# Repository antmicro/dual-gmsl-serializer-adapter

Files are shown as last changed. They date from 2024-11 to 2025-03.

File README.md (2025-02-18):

# Dual Camera to GMSL Serializer CSI Adapter

Copyright (c) 2024-2025 [Antmicro](https://www.antmicro.com)

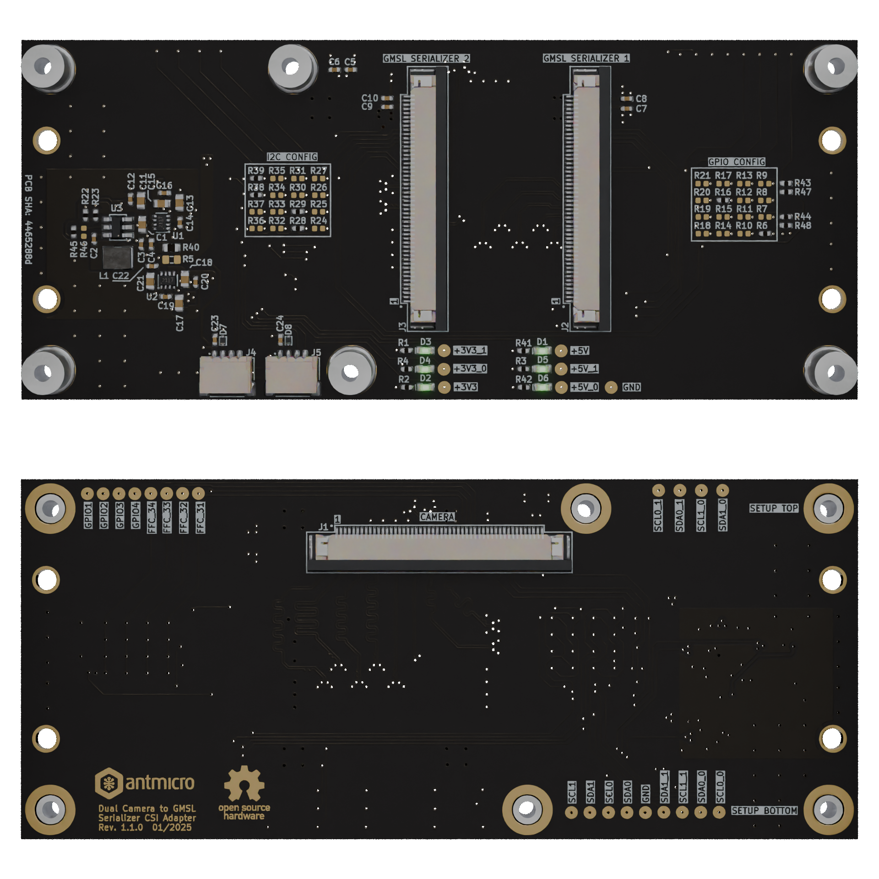
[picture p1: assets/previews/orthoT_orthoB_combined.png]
Dual Camera to GMSL Serializer CSI Adapter visualization


## Overview

This project provides open hardware design files for the Dual Camera to GMSL Serializer CSI Adapter. 
The board is designed to receive two MIPI CSI-2 x2 signals from the [OV5640 Dual Camera Board](https://github.com/antmicro/ov5640-dual-camera-board) and output them to two [GMSL Serializer Boards](https://github.com/antmicro/gmsl-serializer).
The on-board power distribution circuit allows the Dual Camera Board to be powered by one of the selected serializer boards.
The design files were prepared using KiCad 8.x.

## Key features

* 50-pin FFC input connector for the Dual Camera Board connection, exposing two 4-lane MIPI CSI-2 interfaces
* Two 50-pin FFC output connectors for the GMSL Serializer Boards, each supporting a 4-lane MIPI CSI-2 interface
* Two QWIIC connectors for seamless integration of additional I²C devices

## Project structure

The main directory includes KiCad PCB project files, a LICENSE, and a README.
The remaining files are stored in the following directories:

* ``doc`` - contains schematics in PDF format
* ``assets`` - contains visual assets for showcasing this design on [Open Hardware Portal](https://openhardware.antmicro.com) and [System Designer](https://designer.antmicro.com/welcome)

## Licensing

This project is published under the [Apache-2.0](LICENSE) license.

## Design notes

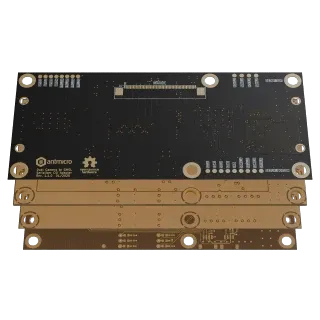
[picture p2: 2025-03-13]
assets/previews/layer1_thumbnail.webp

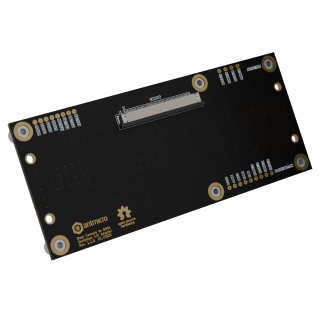
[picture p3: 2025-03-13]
assets/previews/leftT_thumbnail.png

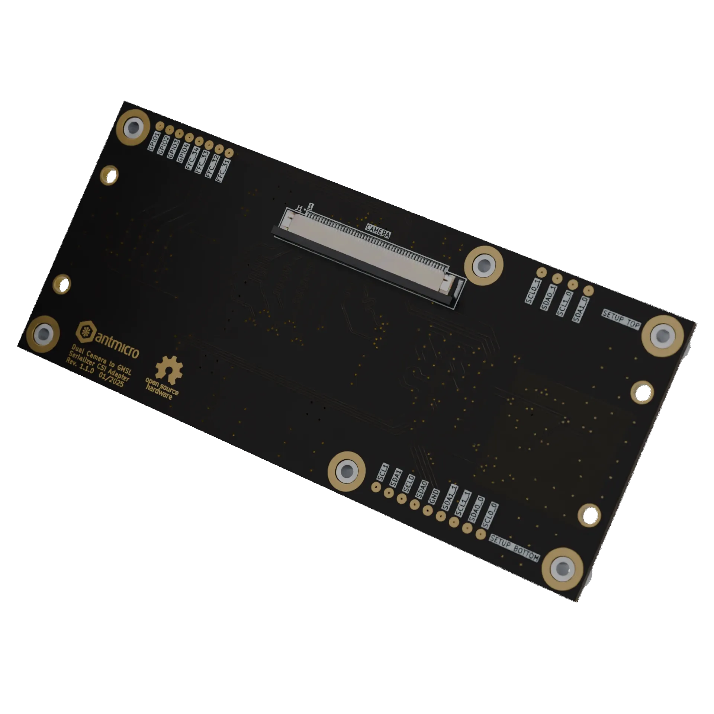
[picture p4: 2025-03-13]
assets/previews/rightT.webp

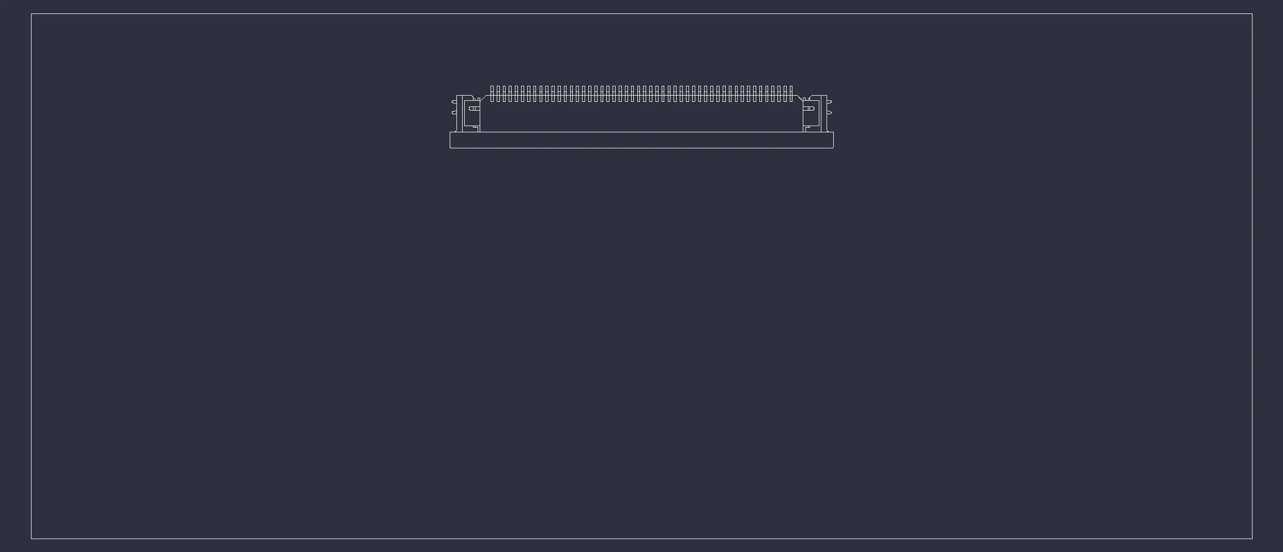
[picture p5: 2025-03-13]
assets/wireframe/wireframe_descriptions_top.webp

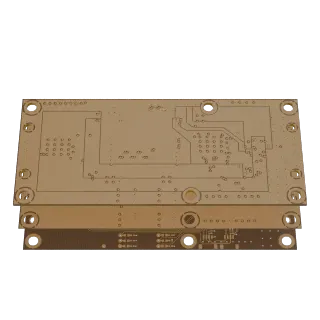
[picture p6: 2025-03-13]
assets/previews/layer3_thumbnail.webp

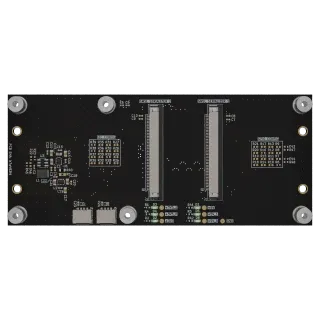
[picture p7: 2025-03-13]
assets/previews/orthoB_thumbnail.webp

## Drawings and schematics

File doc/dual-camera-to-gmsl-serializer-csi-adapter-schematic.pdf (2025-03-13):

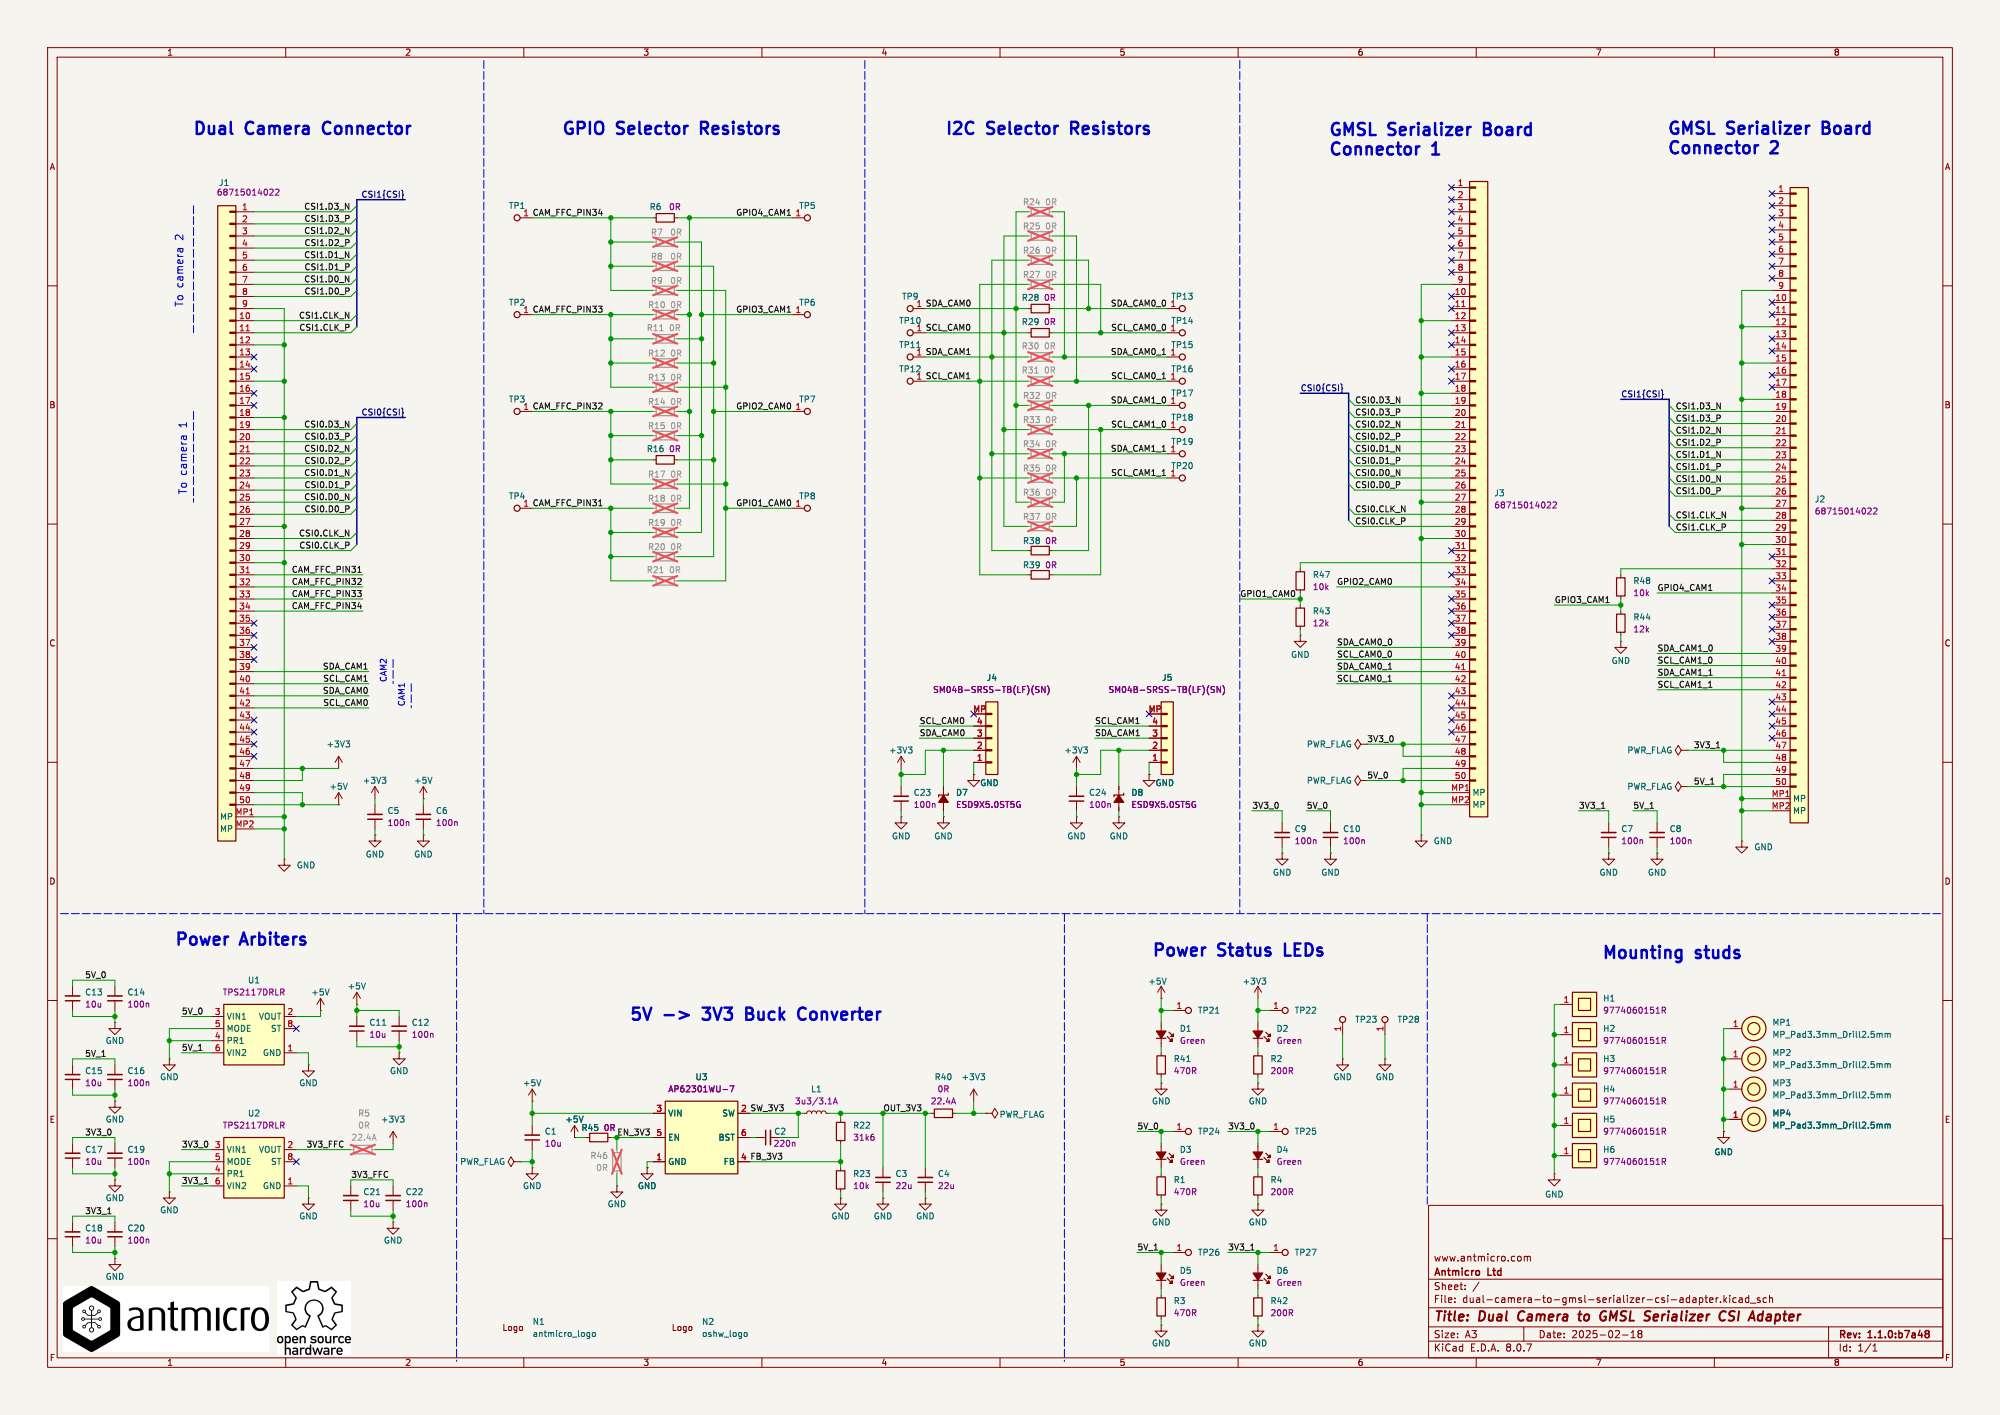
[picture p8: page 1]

J5 SM04B-SRSS-TB(LF)(SN) R37 0R

J4 SM04B-SRSS-TB(LF)(SN) 1

J5 SM04B-SRSS-TB(LF)(SN) 1

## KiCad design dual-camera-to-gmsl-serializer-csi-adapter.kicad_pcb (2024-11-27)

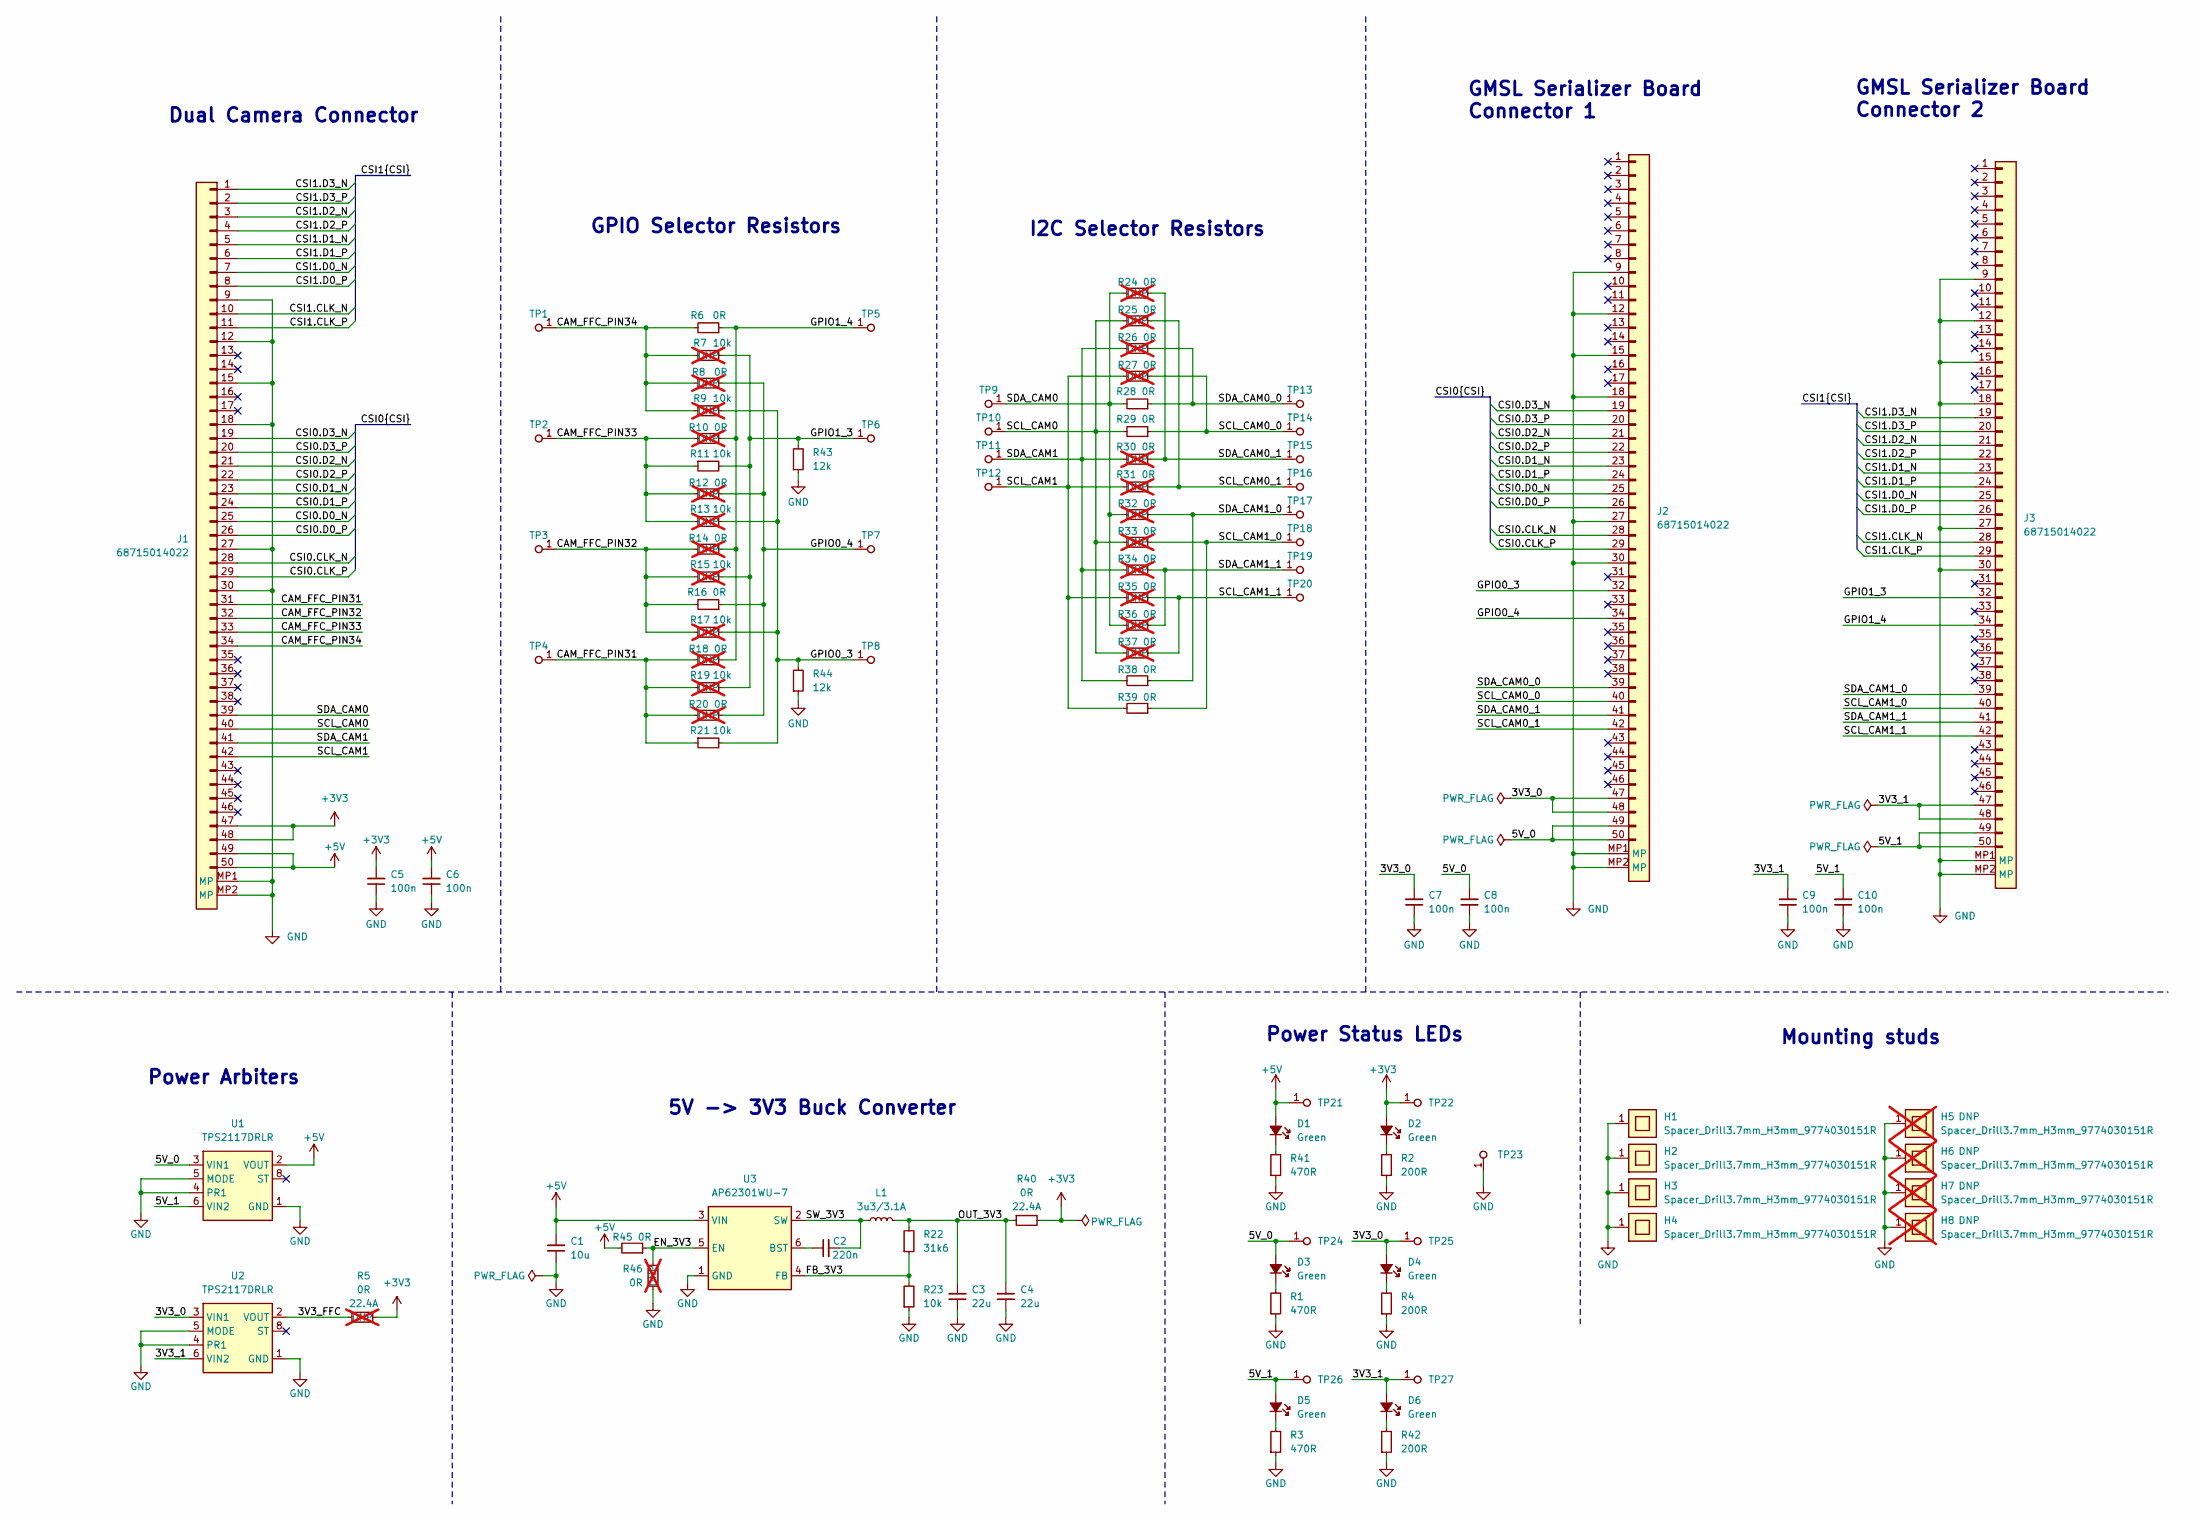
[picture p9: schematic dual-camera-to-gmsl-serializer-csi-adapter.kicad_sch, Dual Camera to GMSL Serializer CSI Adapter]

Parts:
C1: C_10u_25V_0603; C_0603_1608Metric; Voltage 25V; MPN C1608X5R1E106M080AC
C2: C_220n_0402; C_0402_1005Metric; MPN CC0402KRX5R6BB224
C3, C4: C_22u_0402; C_0402_1005Metric; MPN GRM158R60J226ME01D
C5, C6, C7, C8, C9, C10: C_100n_0402; C_0402_1005Metric; Voltage 50V; MPN GRM155R61H104KE14D
D1, D2, D3, D4, D5, D6: LED_G_0603_LTST-C190GKT; LED_0603_1608Metric_G; MPN LTST-C190GKT
H1, H2, H3, H4: Spacer_Drill3.7mm_H3mm_9774030151R; MPN 9774030151R
H5, H6, H7, H8: Spacer_Drill3.7mm_H3mm_9774030151R; MPN 9774030151R; not fitted
J1, J2, J3: Conn_FFC_WE_68715014022; Conn_FFC_WE_68715014x22; MPN 68715014022
L1: L_3u3_3.1A_Bourns-SRP3212A; L_Bourns-SRP3212A; MPN SRP3212-3R3M
R1, R3, R41: R_470R_0402; R_0402_1005Metric; Tolerance 1%; MPN CR0402-FX-4700GLF
R2, R4, R42: R_200R_0402; R_0402_1005Metric; Tolerance 1%; MPN CR0402-FX-2000GLF
R5: R_0R_22.4A_0603; R_0603_1608Metric; Tolerance template_tolerance; MPN PMR03EZPJ000; not fitted
R6, R16, R28, R29, R38, R39, R45: R_0R_0402; R_0402_1005Metric; MPN ERJ2GE0R00X
R7, R9, R13, R15, R17, R19: R_10k_0402; R_0402_1005Metric; Tolerance 1%; MPN CR0402-FX-1002GLF; not fitted
R8, R10, R12, R14, R18, R20, R24, R25, R26, R27, R30, R31, R32, R33, R34, R35, R36, R37, R46: R_0R_0402; R_0402_1005Metric; MPN ERJ2GE0R00X; not fitted
R11, R21, R23: R_10k_0402; R_0402_1005Metric; Tolerance 1%; MPN CR0402-FX-1002GLF
R22: R_31k6_0402; R_0402_1005Metric; Tolerance 1%; MPN CR0402-FX-3162GLF
R40: R_0R_22.4A_0603; R_0603_1608Metric; Tolerance template_tolerance; MPN PMR03EZPJ000
R43, R44: R_12k_0402; R_0402_1005Metric; Tolerance 1%; MPN CR0402-FX-1202GLF
TP1, TP2, TP3, TP4, TP5, TP6, TP7, TP8, TP9, TP10, TP11, TP12, TP13, TP14, TP15, TP16, TP17, TP18, TP19, TP20, TP21, TP22, TP23, TP24, TP25, TP26, TP27: TP_1.5mm_SMD; TP_SMD_1.5mm
U1, U2: TPS2117DRLR; SOT-583; MPN TPS2117DRLR
U3: AP62301_TSOT; TSOT23-6; MPN AP62301WU-7

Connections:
+3V3: C5.2, D2.2 (A), J1.47, J1.48, R5.2, R40.2, TP22.1
+5V: C1.2, C6.2, D1.2 (A), J1.49, J1.50, R45.2, TP21.1, U1.2 (VOUT), U1.7 (VOUT), U3.3 (VIN)
/3V3_0: C7.2, D4.2 (A), J2.47, J2.48, TP25.1, U2.3 (VIN1)
/3V3_1: C9.2, D6.2 (A), J3.47, J3.48, TP27.1, U2.6 (VIN2)
/3V3_FFC: R5.1, U2.2 (VOUT), U2.7 (VOUT)
/5V_0: C8.2, D3.2 (A), J2.49, J2.50, TP24.1, U1.3 (VIN1)
/5V_1: C10.2, D5.2 (A), J3.49, J3.50, TP26.1, U1.6 (VIN2)
/CAM_FFC_PIN31: J1.31, R18.2, R19.1, R20.2, R21.1, TP4.1
/CAM_FFC_PIN32: J1.32, R14.2, R15.1, R16.2, R17.1, TP3.1
/CAM_FFC_PIN33: J1.33, R10.2, R11.1, R12.2, R13.1, TP2.1
/CAM_FFC_PIN34: J1.34, R6.2, R7.1, R8.2, R9.1, TP1.1
/CSI0.CLK_N: J1.28, J2.28
/CSI0.CLK_P: J1.29, J2.29
/CSI0.D0_N: J1.25, J2.25
/CSI0.D0_P: J1.26, J2.26
/CSI0.D1_N: J1.23, J2.23
/CSI0.D1_P: J1.24, J2.24
/CSI0.D2_N: J1.21, J2.21
/CSI0.D2_P: J1.22, J2.22
/CSI0.D3_N: J1.19, J2.19
/CSI0.D3_P: J1.20, J2.20
/CSI1.CLK_N: J1.10, J3.28
/CSI1.CLK_P: J1.11, J3.29
/CSI1.D0_N: J1.7, J3.25
/CSI1.D0_P: J1.8, J3.26
/CSI1.D1_N: J1.5, J3.23
/CSI1.D1_P: J1.6, J3.24
/CSI1.D2_N: J1.3, J3.21
/CSI1.D2_P: J1.4, J3.22
/CSI1.D3_N: J1.1, J3.19
/CSI1.D3_P: J1.2, J3.20
/EN_3V3: R45.1, R46.1, U3.5 (EN)
/FB_3V3: R22.1, R23.2, U3.4 (FB)
/GPIO0_3: J2.32, R9.2, R13.2, R17.2, R21.2, R44.2, TP8.1
/GPIO0_4: J2.34, R8.1, R12.1, R16.1, R20.1, TP7.1
/GPIO1_3: J3.32, R7.2, R11.2, R15.2, R19.2, R43.2, TP6.1
/GPIO1_4: J3.34, R6.1, R10.1, R14.1, R18.1, TP5.1
/OUT_3V3: C3.2, C4.2, L1.2, R22.2, R40.1
/SCL_CAM0: J1.40, R25.2, R29.2, R33.2, R37.2, TP10.1
/SCL_CAM0_0: J2.40, R27.1, R29.1, TP14.1
/SCL_CAM0_1: J2.42, R25.1, R31.1, TP16.1
/SCL_CAM1: J1.42, R27.2, R31.2, R35.2, R39.2, TP12.1
/SCL_CAM1_0: J3.40, R33.1, R39.1, TP18.1
/SCL_CAM1_1: J3.42, R35.1, R37.1, TP20.1
/SDA_CAM0: J1.39, R24.2, R28.2, R32.2, R36.2, TP9.1
/SDA_CAM0_0: J2.39, R26.1, R28.1, TP13.1
/SDA_CAM0_1: J2.41, R24.1, R30.1, TP15.1
/SDA_CAM1: J1.41, R26.2, R30.2, R34.2, R38.2, TP11.1
/SDA_CAM1_0: J3.39, R32.1, R38.1, TP17.1
/SDA_CAM1_1: J3.41, R34.1, R36.1, TP19.1
/SW_3V3: C2.2, L1.1, U3.2 (SW)
GND: C1.1, C3.1, C4.1, C5.1, C6.1, C7.1, C8.1, C9.1, C10.1, H1.1, H2.1, H3.1, H4.1, H5.1, H6.1, H7.1, H8.1, J1.9, J1.12, J1.15, J1.18, J1.27, J1.30, J1.MP1 (MP), J1.MP2 (MP), J2.9, J2.12, J2.15, J2.18, J2.27, J2.30, J2.MP1 (MP), J2.MP2 (MP), J3.9, J3.12, J3.15, J3.18, J3.27, J3.30, J3.MP1 (MP), J3.MP2 (MP), R1.1, R2.1, R3.1, R4.1, R23.1, R41.1, R42.1, R43.1, R44.1, R46.2, TP23.1, U1.1 (GND), U1.4 (PR1), U1.5 (MODE), U2.1 (GND), U2.4 (PR1), U2.5 (MODE), U3.1 (GND)
unnamed: D1.1 (C), R41.2
unnamed: D2.1 (C), R2.2
unnamed: D3.1 (C), R1.2
unnamed: D4.1 (C), R4.2
unnamed: D5.1 (C), R3.2
unnamed: D6.1 (C), R42.2
unnamed: C2.1, U3.6 (BST)

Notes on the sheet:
Power Status LEDs
Power Arbiters
5V -> 3V3 Buck Converter
I2C Selector Resistors
GPIO Selector Resistors
GMSL Serializer Board Connector 1
Dual Camera Connector
GMSL Serializer Board Connector 2
Mounting studs

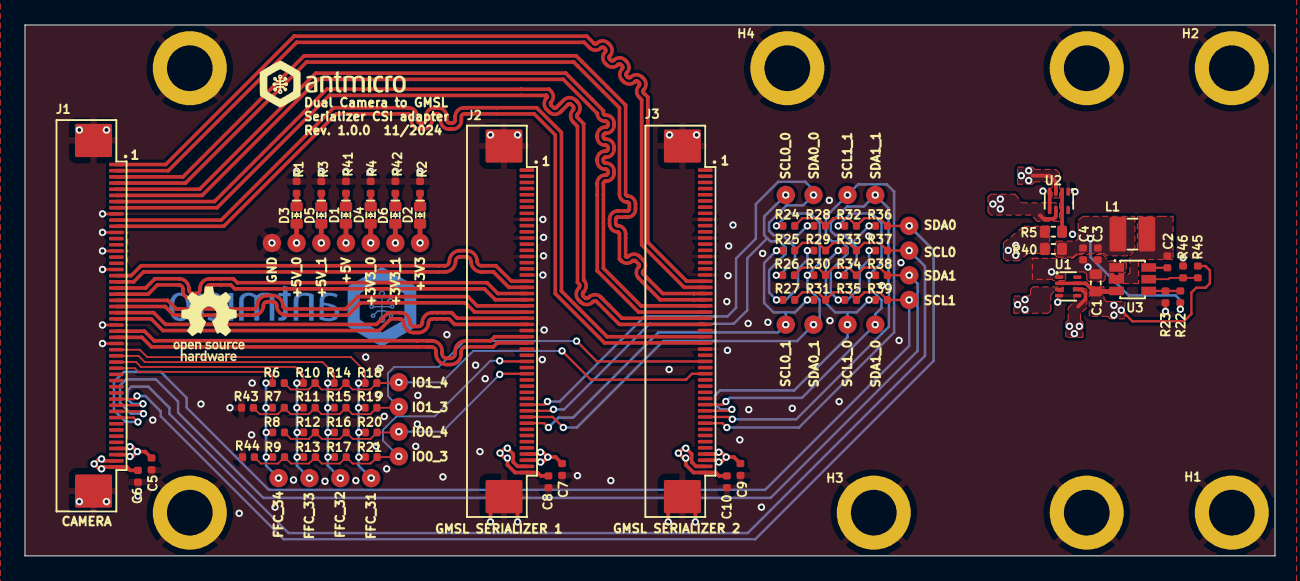
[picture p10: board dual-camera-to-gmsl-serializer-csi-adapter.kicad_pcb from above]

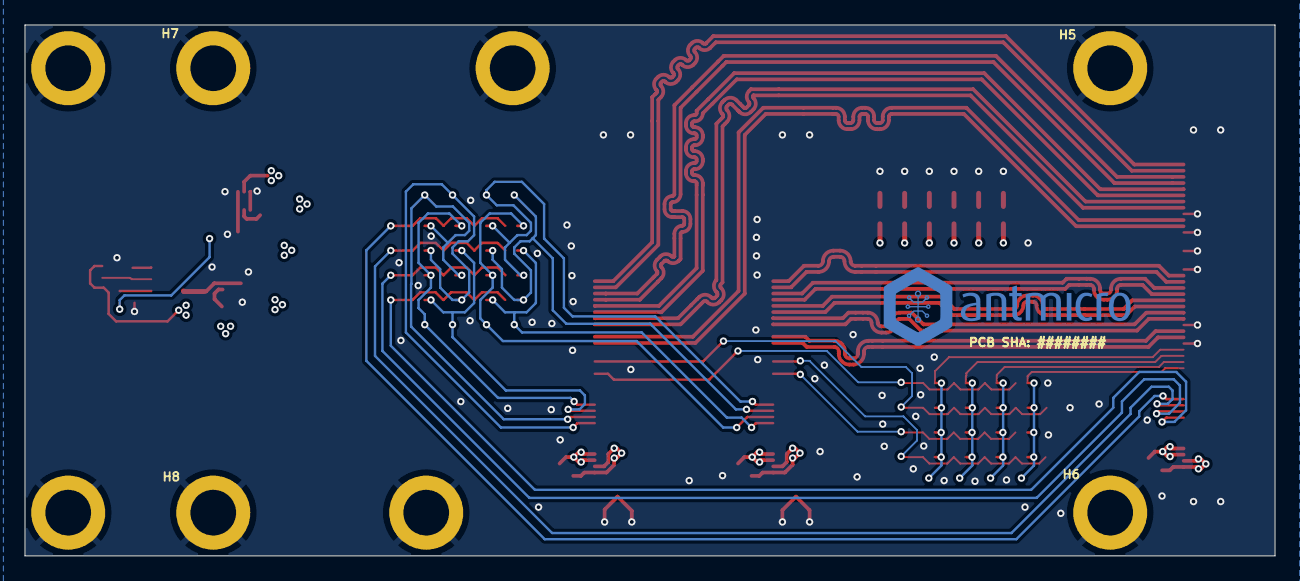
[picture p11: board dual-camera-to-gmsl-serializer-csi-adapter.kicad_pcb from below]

Board: 4 copper layers, 101.2 x 43.0 mm, 104 parts (4 on the bottom side), 59 nets.

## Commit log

2024-11-22 [#69172] Add project, license and readme
    [dual-camera-to-gmsl-serializer-csi-adapter.kicad_pcb, dual-camera-to-gmsl-serializer-csi-adapter.kicad_sch]
2024-11-22 [#69172] Add connectors and buck converter to schematics
    [dual-camera-to-gmsl-serializer-csi-adapter.kicad_sch]
2024-11-25 [#69172] Add resistor selectors
    [dual-camera-to-gmsl-serializer-csi-adapter.kicad_sch]
2024-11-26 [#69172] Transfer schematic onto pcb
    [dual-camera-to-gmsl-serializer-csi-adapter.kicad_pcb, dual-camera-to-gmsl-serializer-csi-adapter.kicad_sch]
2024-11-26 [#69172] Rotate FFC connectors
    [dual-camera-to-gmsl-serializer-csi-adapter.kicad_pcb]
2024-11-26 [#69172] Add power planes
    [dual-camera-to-gmsl-serializer-csi-adapter.kicad_pcb]
2024-11-27 [#69172] Update schematics
    [dual-camera-to-gmsl-serializer-csi-adapter.kicad_pcb, dual-camera-to-gmsl-serializer-csi-adapter.kicad_sch]
2024-11-27 [#69172] Update PCB
    [dual-camera-to-gmsl-serializer-csi-adapter.kicad_pcb, dual-camera-to-gmsl-serializer-csi-adapter.kicad_sch]
2024-11-27 [#69172] Update components
    [dual-camera-to-gmsl-serializer-csi-adapter.kicad_sch]
2024-11-27 [#69172] Add post-review fixes
    [dual-camera-to-gmsl-serializer-csi-adapter.kicad_sch]
2024-11-27 [#69172] Clean ERC, add GND vias
2024-11-28 [#69172] Add assets and doc
    [stackup.csv]
2024-11-28 [#69474] Fix silkscreen
2024-12-18 [#70359] Move camera connector to bottom side
    [dual-camera-to-gmsl-serializer-csi-adapter.kicad_sch]
2024-12-19 [#70359] PCB: Extend PCB width
2025-02-17 [#70359] PCB: Align spacers with camera board
    [dual-camera-to-gmsl-serializer-csi-adapter.kicad_sch]
2025-02-17 [#70359] PCB: Rotate 180deg and move J1
2025-02-17 [#70359] PCB: Add camera board mechanical mockup
2025-02-17 [#70359] Add TODOs after first review
    [dual-camera-to-gmsl-serializer-csi-adapter.kicad_sch]
2025-02-17 [#70359] PCB: Rotate board
2025-02-17 [#70359] PCB: Update OV5640 mounting holes
    [dual-camera-to-gmsl-serializer-csi-adapter.kicad_sch]
2025-02-17 [#70359] PCB: Add fastening holes
    [dual-camera-to-gmsl-serializer-csi-adapter.kicad_sch]
2025-02-17 [#70359] PCB: Remove legacy HS tracks
2025-02-17 [#70359] Schematic: Resolve I2C mapping
    [dual-camera-to-gmsl-serializer-csi-adapter.kicad_sch]
2025-02-17 [#70359] Schematic: Resolve GPIO naming
    [dual-camera-to-gmsl-serializer-csi-adapter.kicad_sch]
2025-02-17 [#70359] Schematic: Add OSHW & Antmicro logos
    [dual-camera-to-gmsl-serializer-csi-adapter.kicad_sch]
2025-02-17 [#70359] Schematic: Add I2C Qwiic connectors
    [dual-camera-to-gmsl-serializer-csi-adapter.kicad_sch]
2025-02-17 [#70359] Schematic: Swap J2 with J3
    [dual-camera-to-gmsl-serializer-csi-adapter.kicad_sch]
2025-02-17 [#70359] PCB: Set stackup to ec-defined-impedance-4L
2025-02-17 [#70359] PCB: Add 100Zout and 100Zinner netclasses
2025-02-17 [#70359] PCB: Cleanup legacy tracks/vias
2025-02-17 [#70359] PCB: Position TPs and logos
    [dual-camera-to-gmsl-serializer-csi-adapter.kicad_sch]
2025-02-17 [#70359] PCB: Try initial routing
    [dual-camera-to-gmsl-serializer-csi-adapter.kicad_sch]
2025-02-17 [#70359] PCB: Swap J1&J2 power planes
    [dual-camera-to-gmsl-serializer-csi-adapter.kicad_sch]
2025-02-17 [#70359] PCB: Add GND testpoints to both sides
    [dual-camera-to-gmsl-serializer-csi-adapter.kicad_sch]
2025-02-17 [#70359] PCB: Add stackup table
2025-02-17 [#70924] Add ov camera module step
2025-02-17 [#70924] Link ov step in pcb
2025-02-17 [#72052] Add connector alignment dimensions
2025-02-17 [#72052] Add camera spacers to BOM
    [dual-camera-to-gmsl-serializer-csi-adapter-BOM-populated.csv]
2025-02-17 [#72052] Resolve 5V0, 5V1, 3V0, 3V1 routing
    [dual-camera-to-gmsl-serializer-csi-adapter.kicad_sch]
2025-02-17 [#72052] Resolve 5V,3V3 routing
2025-02-17 [#72052] Extend power planes and add GND fill on IN2
2025-02-17 [#72052] Fix connections to power planes
2025-02-17 [#72052] Remove GND fills on top & bot
2025-02-17 [#72052] Increase HS to power zones spacing
2025-02-17 [#72052] Add supply gnd zone
2025-02-17 [#72052] Improve 5V & 3V breakout
2025-02-17 [#72052] Widen GND tracks
2025-02-17 [#72052] Update 5V plane
2025-02-17 [#72052] Update OHP assets
    [dual-camera-to-gmsl-serializer-csi-adapter-BOM-populated.csv, stackup.csv]
2025-02-18 [#70359] Tweak routing, DRC clean
    [dual-camera-to-gmsl-serializer-csi-adapter.kicad_sch]
2025-02-18 [#70359] Re-generate schematic

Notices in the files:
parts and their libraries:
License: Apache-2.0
